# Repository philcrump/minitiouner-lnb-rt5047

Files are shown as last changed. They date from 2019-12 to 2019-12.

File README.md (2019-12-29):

# minitiouner-lnb-rt5047

This is a PCB for a 13V/18V LNB Bias Voltage supply, designed to be used with the Minitiouner V2 hardware. A single regulator is present however this can easily supply 100mA LNBs on both channels.

Inputs are available for Enable/Disable, and 13V/18V selection. An output for a "Fault" LED indicator is also available.

22KHz tone feature requires an external modulator, an input is available for this, however it has not been tested by the author.

[Schematic PDF file](https://github.com/philcrump/minitiouner-lnb-rt5047/raw/master/minitiouner-rt5047.pdf)

## PCB Images

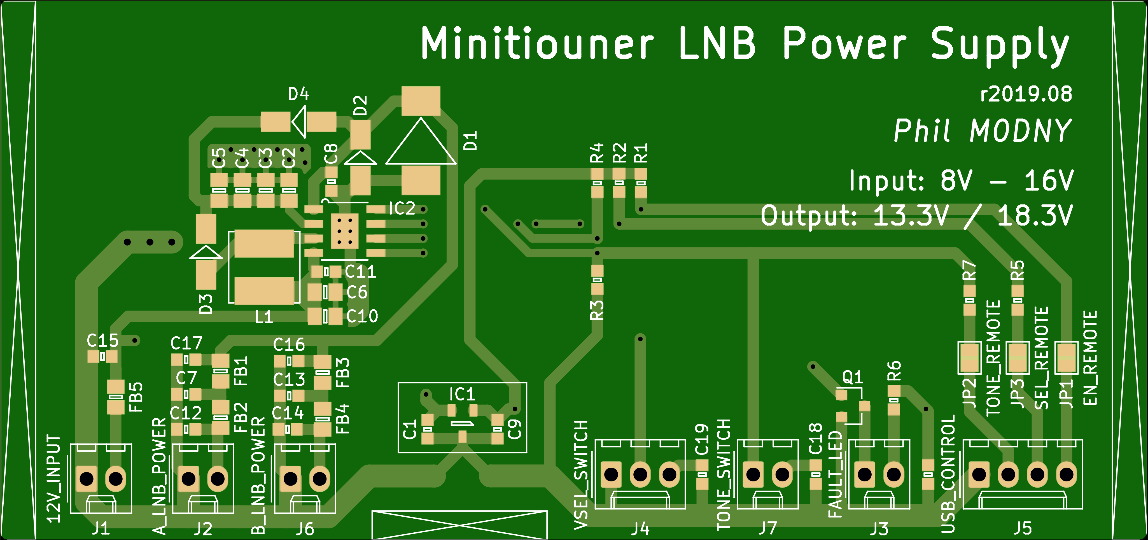
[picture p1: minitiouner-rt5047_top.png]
PCB Top


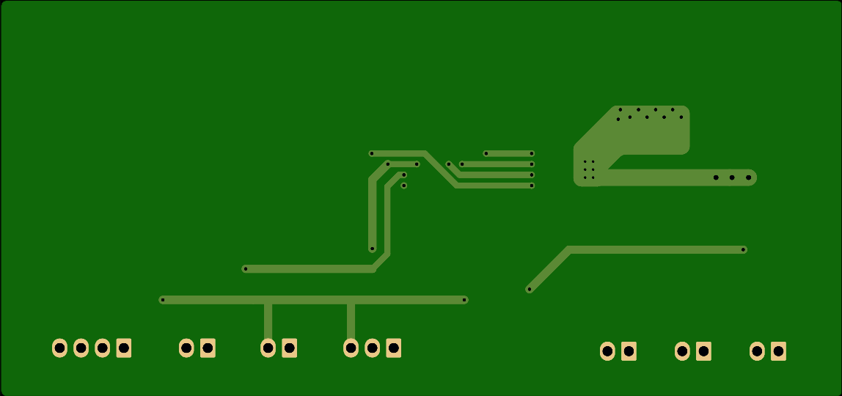
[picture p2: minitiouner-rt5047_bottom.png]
PCB Bottom


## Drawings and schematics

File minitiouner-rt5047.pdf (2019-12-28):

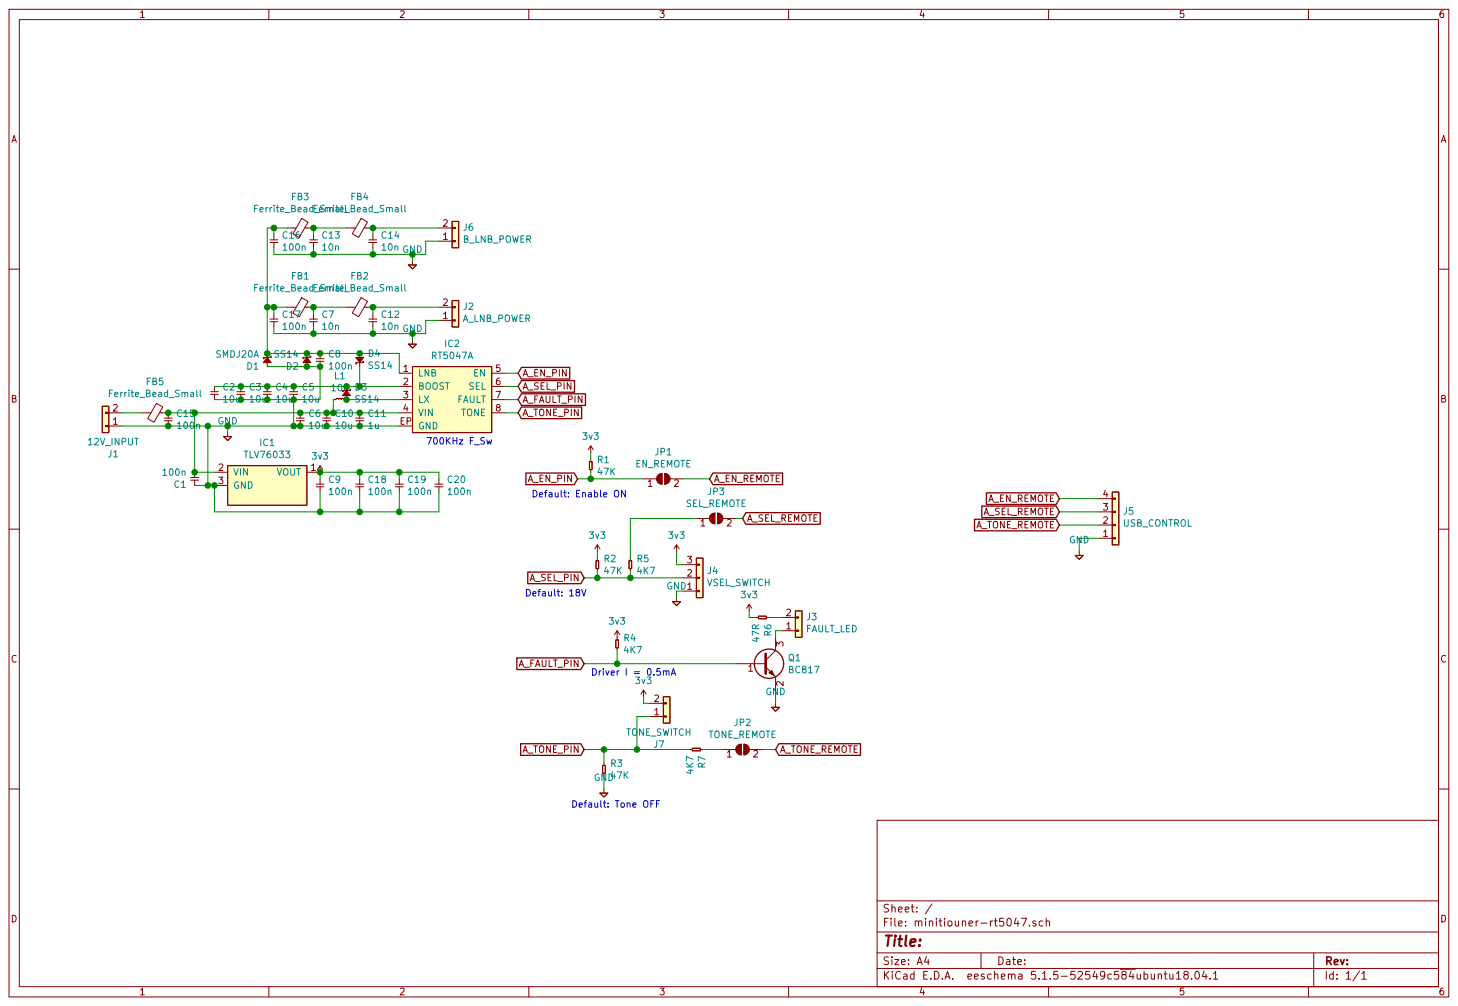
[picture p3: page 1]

A_EN_PIN
Default: 18V Default: Enable ON

Default: Tone OFF Driver I = 0.5mA

Id: 1/1 Title: File: minitiouner-rt5047.sch Sheet: /

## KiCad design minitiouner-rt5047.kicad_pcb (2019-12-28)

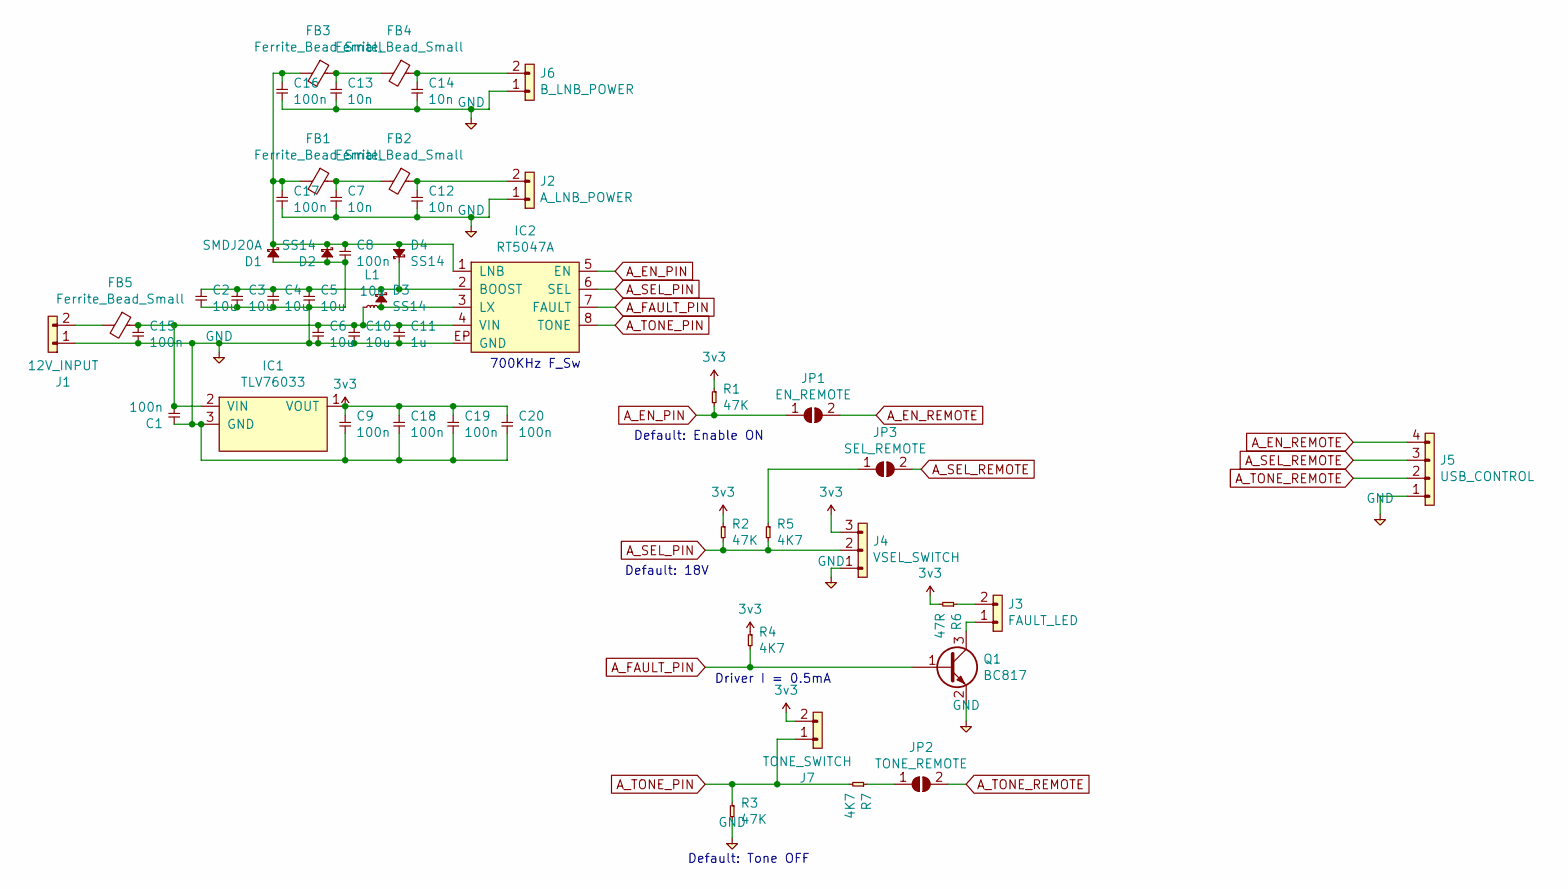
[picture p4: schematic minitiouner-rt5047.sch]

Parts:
C1, C8, C9, C15, C16, C17, C18, C19, C20: 100n; 0603
C2, C3, C4, C5, C6, C10: 10u; 0805
C7, C12, C13, C14: 10n; 0603
C11: 1u; 0603
D1: SMDJ20A; DO-214AB-SMC; Farnell 2777300
D2, D3, D4: SS14; DO-214AC-SMA
FB1, FB2, FB3, FB4, FB5: Ferrite_Bead_Small; 0805; FARNELL 2859031
IC1: TLV76033; SOT-23; Farnell 2773545
IC2: RT5047A; SOIC-8-EP; Farnell 2545957
J1: 12V_INPUT; Molex_KK-254_AE-6410-02A_1x02_P2.54mm_Vertical
J2: A_LNB_POWER; Molex_KK-254_AE-6410-02A_1x02_P2.54mm_Vertical
J3: FAULT_LED; Molex_KK-254_AE-6410-02A_1x02_P2.54mm_Vertical
J4: VSEL_SWITCH; Molex_KK-254_AE-6410-03A_1x03_P2.54mm_Vertical
J5: USB_CONTROL; Molex_KK-254_AE-6410-04A_1x04_P2.54mm_Vertical
J6: B_LNB_POWER; Molex_KK-254_AE-6410-02A_1x02_P2.54mm_Vertical
J7: TONE_SWITCH; Molex_KK-254_AE-6410-02A_1x02_P2.54mm_Vertical
JP1: EN_REMOTE; SolderJumper-2_P1.3mm_Open_Pad1.0x1.5mm
JP2: TONE_REMOTE; SolderJumper-2_P1.3mm_Open_Pad1.0x1.5mm
JP3: SEL_REMOTE; SolderJumper-2_P1.3mm_Open_Pad1.0x1.5mm
L1: 10u; L_Bourns_SRN6045TA; FARNELL 2061652
Q1: BC817; SOT-23; FARNELL 1902482
R1, R2, R3: 47K; 0603
R4, R5, R7: 4K7; 0603
R6: 47R; 0603

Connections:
3v3: C9.1, C18.1, C19.1, C20.1, IC1.1 (VOUT), J4.3, J7.2, R1.1, R2.1, R4.1, R6.2
A_EN_PIN: IC2.5 (EN), JP1.1 (A), R1.2
A_EN_REMOTE: J5.4, JP1.2 (B)
A_FAULT_PIN: IC2.7 (FAULT), Q1.1 (B), R4.2
A_SEL_PIN: IC2.6 (SEL), J4.2, R2.2, R5.2
A_SEL_REMOTE: J5.3, JP3.2 (B)
A_TONE_PIN: IC2.8 (TONE), J7.1, R3.1, R7.2
A_TONE_REMOTE: J5.2, JP2.2 (B)
GND: C1.1, C2.2, C3.2, C4.2, C5.2, C6.2, C7.2, C8.2, C9.2, C10.2, C11.2, C12.2, C13.2, C14.2, C15.2, C16.2, C17.2, C18.2, C19.2, C20.2, D1.2, D2.2, IC1.3 (GND), IC2.EP (GND), J1.1, J2.1, J4.1, J5.1, J6.1, Q1.2 (E), R3.2
unnamed: C1.2, C6.1, C10.1, C11.1, C15.1, FB5.1, IC1.2 (VIN), IC2.4 (VIN), L1.1
unnamed: C2.1, C3.1, C4.1, C5.1, D3.1, D4.1, IC2.2 (BOOST)
unnamed: C7.1, FB1.1, FB2.2
unnamed: C12.1, FB2.1, J2.2
unnamed: C13.1, FB3.1, FB4.2
unnamed: C14.1, FB4.1, J6.2
unnamed: C8.1, C16.1, C17.1, D1.1, D2.1, D4.2, FB1.2, FB3.2, IC2.1 (LNB)
unnamed: D3.2, IC2.3 (LX), L1.2
unnamed: FB5.2, J1.2
unnamed: J3.1, Q1.3 (C)
unnamed: J3.2, R6.1
unnamed: JP2.1 (A), R7.1
unnamed: JP3.1 (A), R5.1

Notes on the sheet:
Driver I = 0.5mA
700KHz F_Sw
Default: Tone OFF
Default: Enable ON
Default: 18V

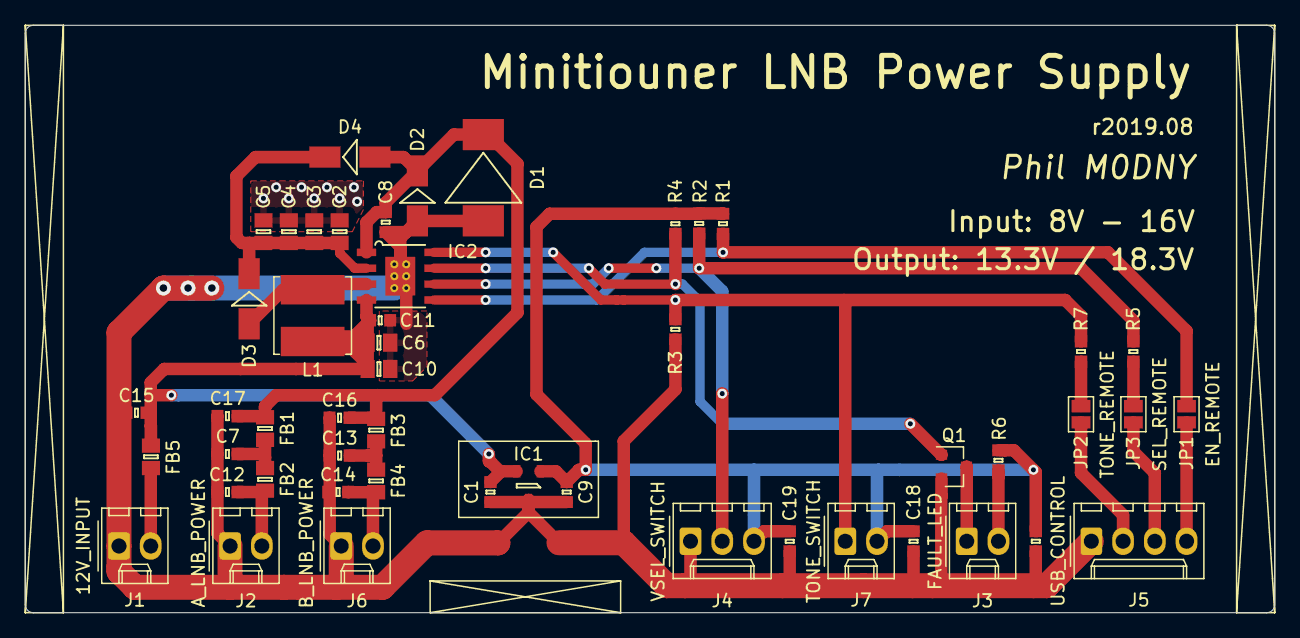
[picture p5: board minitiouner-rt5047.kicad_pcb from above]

Board: 2 copper layers, 99.9 x 47.0 mm, 50 parts (0 on the bottom side), 22 nets.

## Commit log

2019-08-20 Start sch.
    [minitiouner-rt5047.kicad_pcb, minitiouner-rt5047.sch]
2019-12-28 Update to correct philcrump/agg-kicad ref.
2019-12-28 Add final changes and fabrication output.
    [minitiouner-rt5047-B_Cu.gbl, minitiouner-rt5047-B_Mask.gbs, minitiouner-rt5047-B_Paste.gbp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]
2019-12-28 Add schematic, top & bottom pcb; renders.
